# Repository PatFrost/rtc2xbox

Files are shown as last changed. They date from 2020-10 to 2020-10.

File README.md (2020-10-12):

# RTC2Xbox
<p align="center">
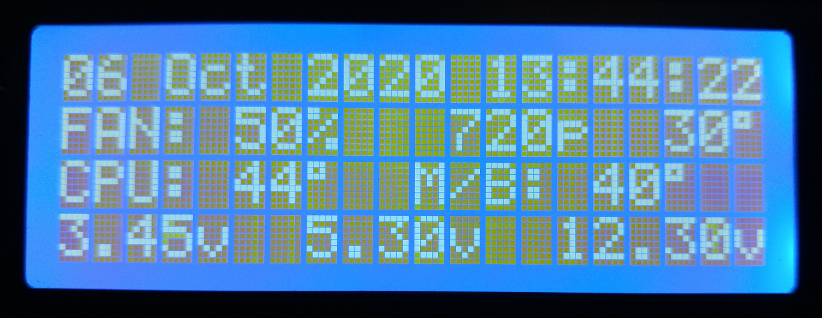
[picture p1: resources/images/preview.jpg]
Preview
  
</p>

<p align="center">
  
  
  <a href="http://hits.dwyl.com/PatFrost/rtc2xbox">HitCount</a>
</p>
<p align="center">
  
  
  
</p>

RTC2Xbox is inspired and based on [spi2par2019](https://github.com/Ryzee119/spi2par2019) by Ryzee119.
<br>It's a LCD mod for the original Xbox without modchip.

# New Features!
  - Display date and time with real time clock.
  - Display temperature ambient from a thermistor.
  - Display voltages 3.3v 5.0v 12.0v

**Note**
  - Delay for displaying fan speed, temp° of CPU, M/B and resolution is 2 secs to 30 secs for first time.
    <br>And the next times is 2 secs to 10 secs. It's depend of the SMBus if is busy or not.
  - Contrast and backlight are controlled by only one potentiometer in same time.

### Parts list
| Part | Qty | Shops | Optional |
| ---- | :----: | ----- | ----- |
| Arduino Pro Micro Leonardo **5V/16Mhz** | **2** | [Any clones will work](https://www.amazon.com/s?k=Arduino+Pro+Micro+Leonardo+5V%2F16Mhz&ref=nb_sb_noss)<br> Make sure they're the **5V/16Mhz** variant. |
| Adafruit **DS1307** Real Time Clock  | **1** | [Any clones will work](https://www.amazon.com/Adafruit-3296-DS1307-Clock-Breakout/dp/B01MG3NEWF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) <br>I don't recommend chinese versions. 1 of 10 work correctly. |
| LCD 2004 | **1** | [Any LCD 20x4 will work](https://www.amazon.com/s?k=LCD+2004&ref=nb_sb_noss) <br>If IIC/I2C/TWI Serial Interface Adapter is present, remove it. |
| Resistor 10kΩ | **6** |[Any Resistor 10kΩ](https://www.amazon.com/BOJACK-Single-Resistor-Resistors-200pcs/dp/B07PGHP69F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) <br>Or any resistor in series with total values 10kΩ |
| Resistor 25kΩ | **1** | [Any Resistor 25kΩ](https://www.amazon.com/s?k=Resistor+25k%E2%84%A6&ref=nb_sb_noss) <br>Or any resistor in series with total values 25kΩ |
| Thermistor 10kΩ | **1** | [Any Thermistor 10kΩ](https://www.amazon.com/s?k=Thermistor+10k%E2%84%A6&s=price-asc-rank&qid=1602342606&ref=sr_st_price-asc-rank) | **Optional** |
| Potentiometer 10kΩ | **1** |[Any Potentiometer 10kΩ](https://www.amazon.com/s?k=Potentiometer+10k%E2%84%A6&ref=nb_sb_noss)|
| Capacitor 220uf | **1** | [Any Capacitor](https://www.amazon.com/s?k=Capacitor+220uf&ref=nb_sb_noss) | **Optional** |
| Connector Plug 4 pin | **1** | [Any 4 Pin Connector Plug Female & Male.](https://www.amazon.com/2-0MM-Female-Single-Connector-Wires/dp/B0732MMD7K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) |
| Perforated Proto Board | **1** | [Any proto board](https://www.amazon.com/s?k=perfboard&ref=nb_sb_noss) | **Optional** |
| Some Wires | **∞** | [Any wires](https://www.amazon.com/s?k=wires+26+AWG&ref=nb_sb_noss) |

### Software Installation
RTC2Xbox uses the open-source Arduino Software (IDE):
  - [Download the Arduino IDE](https://www.arduino.cc/en/Main/Software#download) And install it!

**LiquidCrystal Library**
Open the IDE and click to the "Sketch" menu and then Include Library > [Manage Libraries.](https://www.arduino.cc/en/guide/libraries#toc3)
1. In `Filter your search...` enter `LiquidCrystal` install it or update it.
2. In `Type` select `updatable` and update all libraries which would appear.

**RTC2Xbox Library**
  - [Clone this repository to your PC](https://github.com/PatFrost/rtc2xbox.git)
  - [Or Download Zip](https://github.com/PatFrost/rtc2xbox/archive/master.zip)
    <br>Extract to `rtc2xbox` or rename `rtc2xbox-master` to `rtc2xbox`

### RTC Installation & Programming
1. **Connect Slave (Pro Micro) to RTC DS1307** 
    <br><br>
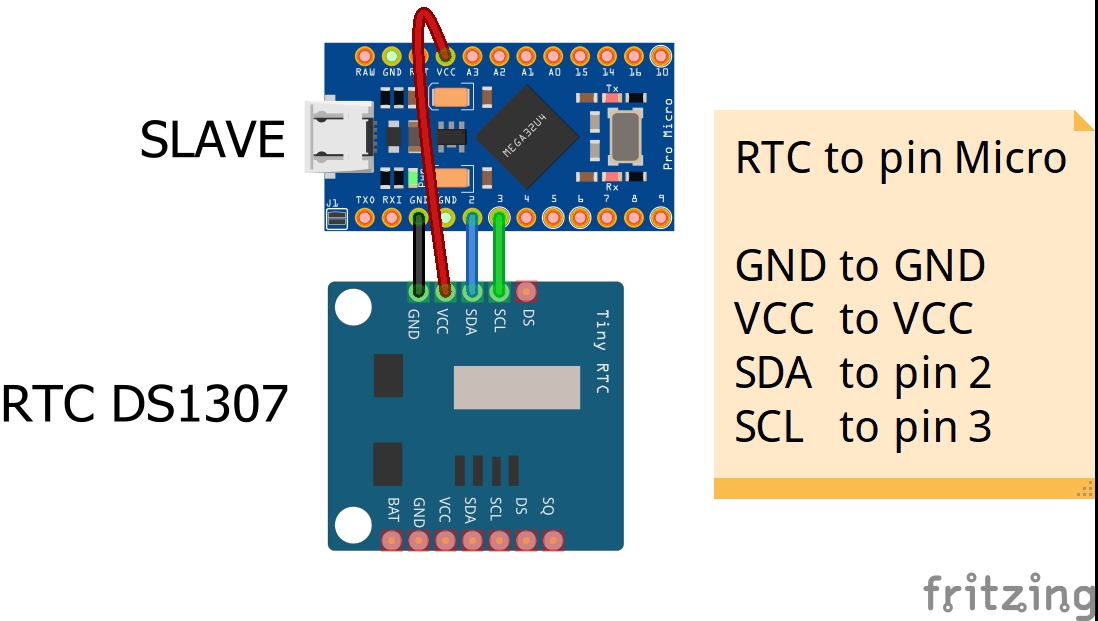
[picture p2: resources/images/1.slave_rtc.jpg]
    
    <br><br><br>
2. **Program Slave (Pro Micro), open `/rtc2xbox/rtc2xbox_slave/rtc2xbox_slave.ino` with Arduino IDE.**<br>
    Uncomment below, if you want force adjust date time.
    Only set the datetime one time.
    ```c++
    // #define FORCE_ADJUST_DATETIME
    ```
    for
    ```c++
    #define FORCE_ADJUST_DATETIME
    ```
    and ajust time at line 30. You can add 30 sec for compiling and uploading.
    ```c++
    uint8_t hour  =   11; // 0-23
    uint8_t min   =    0; // 0-59
    uint8_t sec   =    0; // 0-59

    uint8_t day   =   10; // 1-31
    uint8_t month =   10; // 1-12
    uint16_t year = 2020; // 2000-2099
    ```
    
3. **Set the Board Type the Arduino Leonardo and the port correctly.**
    <br><br>
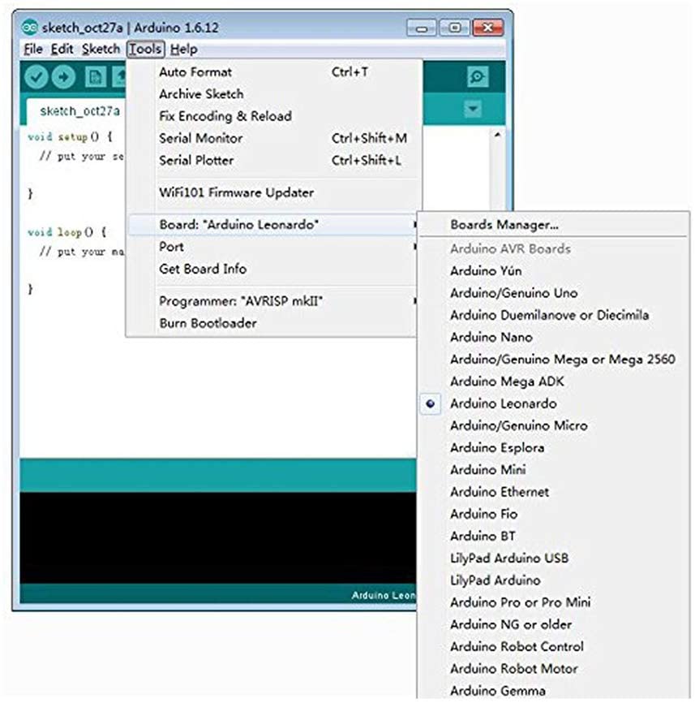
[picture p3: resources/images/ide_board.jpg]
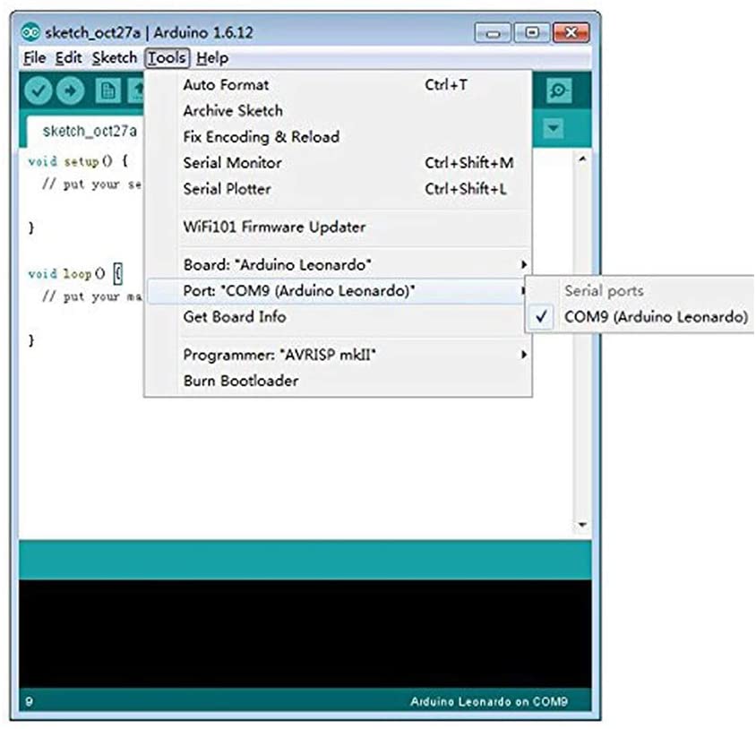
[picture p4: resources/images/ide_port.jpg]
    
    <br><br><br>
4. **Compile by clicking the tick in the top left.**<br>
    Check the console output it has compiled successfully
5. **Connect a Micro USB cable between the Slave (Pro Micro) and the PC.**
6. **Click the upload button and confirm successful.**
7. **Disconnect Slave (Pro Micro)**
    * comment `#define FORCE_ADJUST_DATETIME`. Remember, only set the datetime one time.
        ```c++
        // #define FORCE_ADJUST_DATETIME
        ```
****
8. **Program Master (Pro Micro), open `/rtc2xbox/rtc2xbox.ino` with Arduino IDE.**<br>
    Uncomment below to make the in-game temp readouts display in Fahrenheit.
    ```c++
    // #define USE_FAHRENHEIT
    ```
    for
    ```c++
    #define USE_FAHRENHEIT
    ```
9. **Compile by clicking the tick in the top left.**<br>
    Check the console output it has compiled successfully
10. **Connect a Micro USB cable between the Master (Pro Micro) and the PC.**
11. **Click the upload button and confirm successful.**
12. **Disconnect Master (Pro Micro)**

### Hardware Installation
1. **Connect Master (Pro Micro) to LCD, Potentiometer and Thermistor (Optional)**
    <br><br>
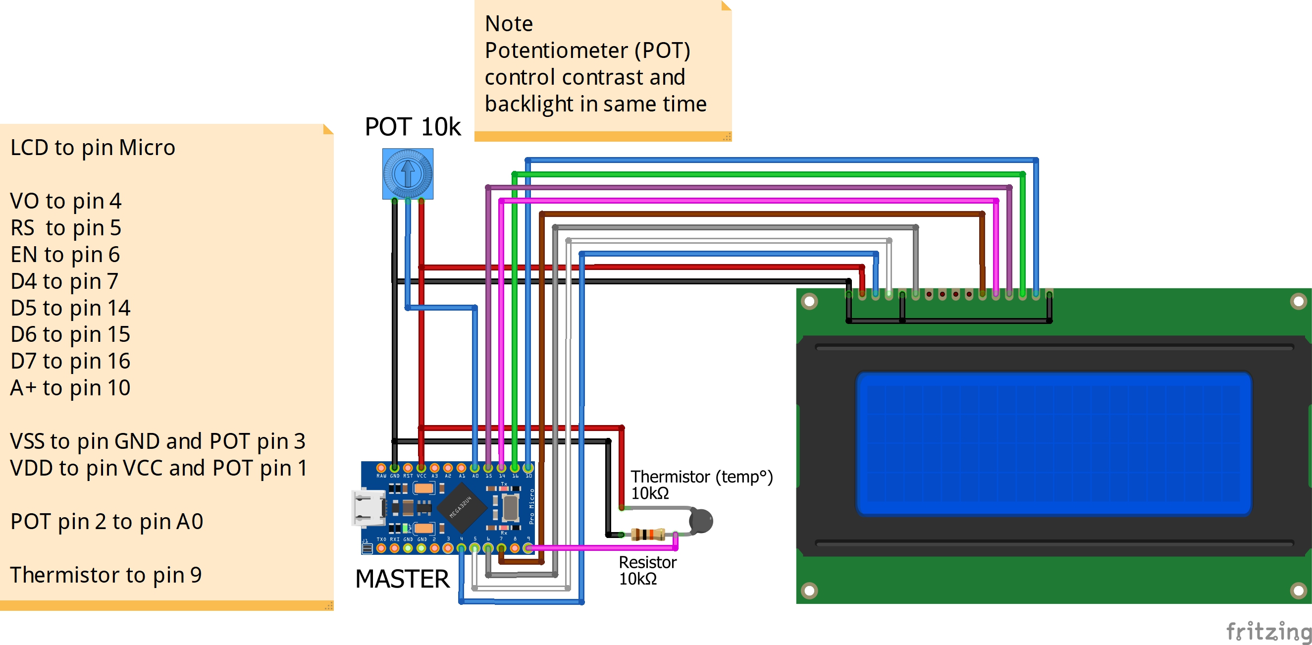
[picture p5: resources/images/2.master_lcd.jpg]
    
    <br><br><br>
2. **Connect Master (Pro Micro) for voltages reading**
    <br><br>
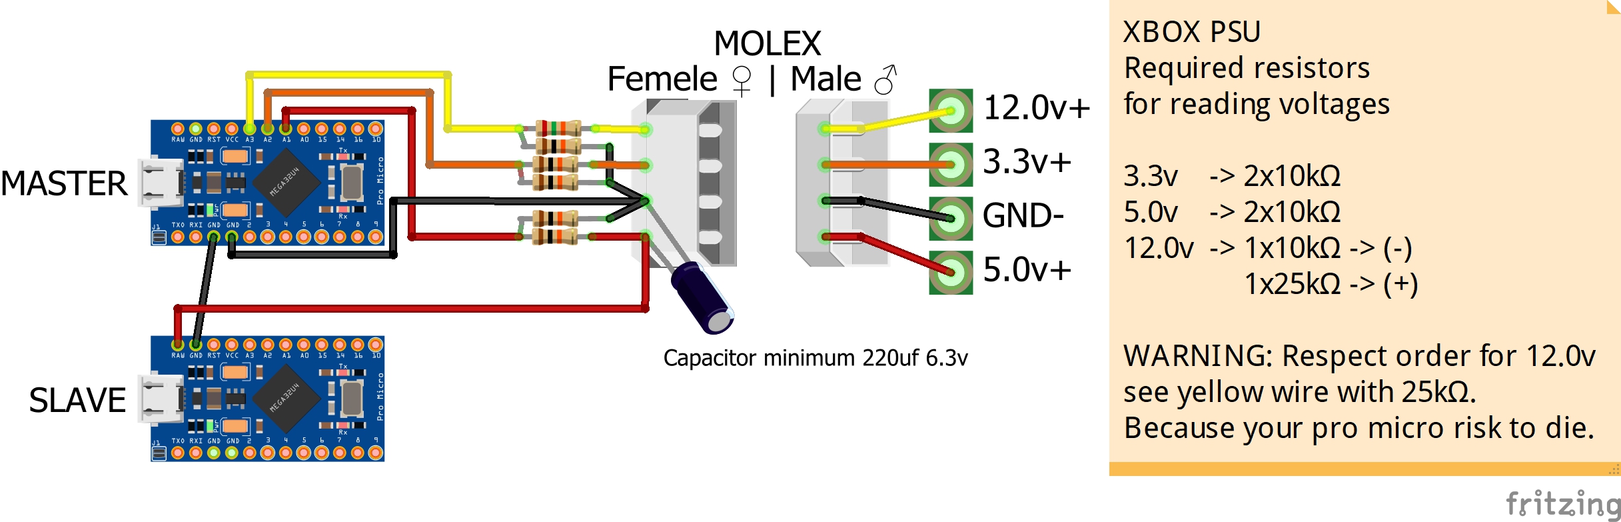
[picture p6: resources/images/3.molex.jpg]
    
    <br><br><br>
3. **Connect Master (Pro Micro) to Slave (Pro Micro)**
    <br><br>
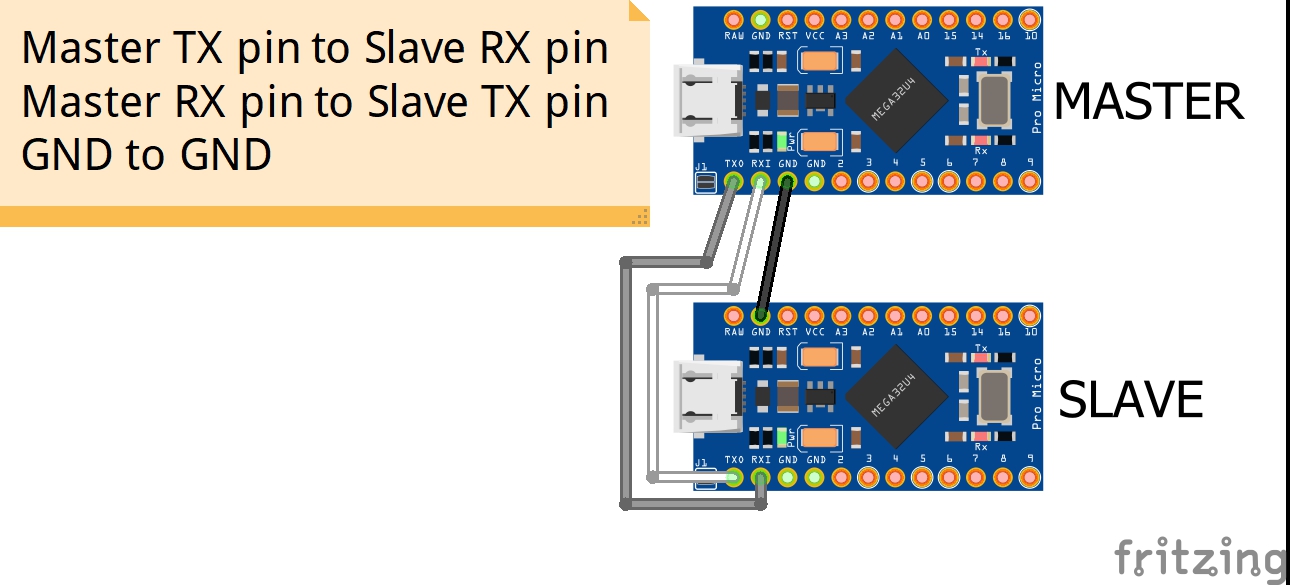
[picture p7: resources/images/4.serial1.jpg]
    
    <br><br><br>
4. **Connect Master (Pro Micro) to Xbox LPC**
    <br><br>
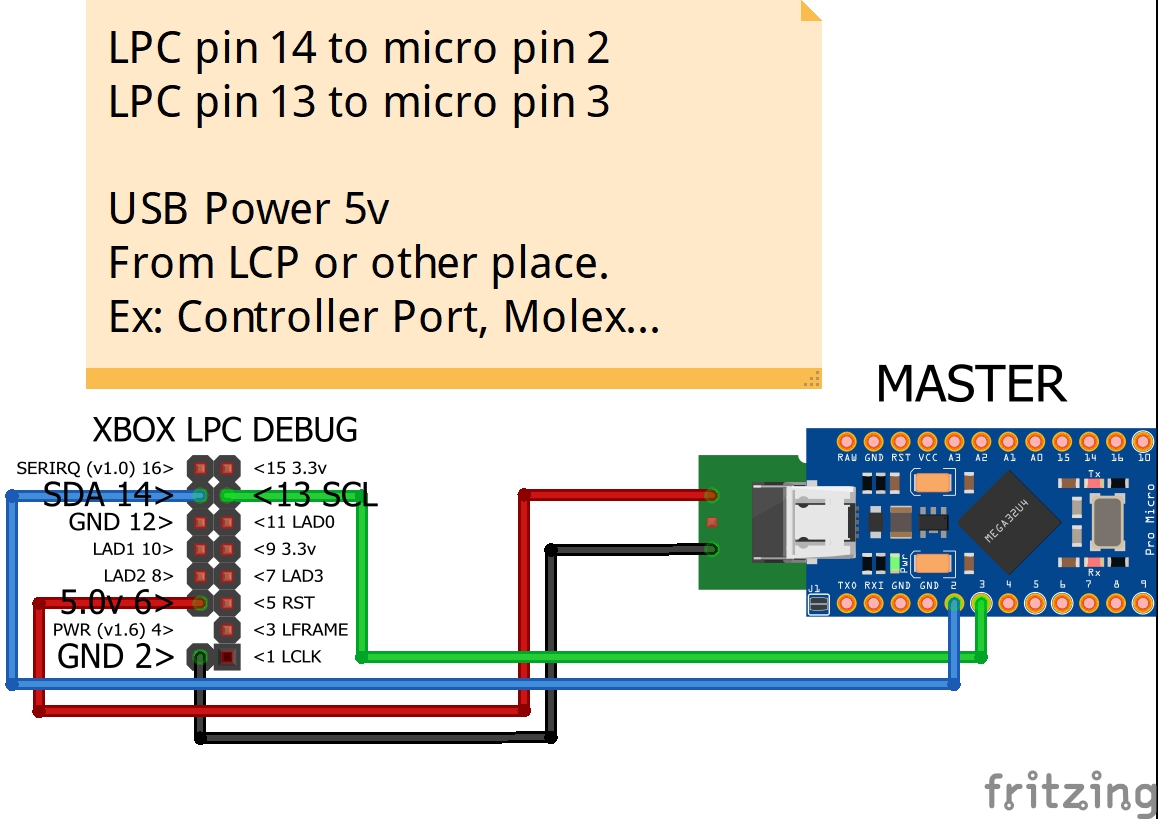
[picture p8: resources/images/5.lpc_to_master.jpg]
    
    <br><br><br>
****
<br><br>
**Final Result**<br>
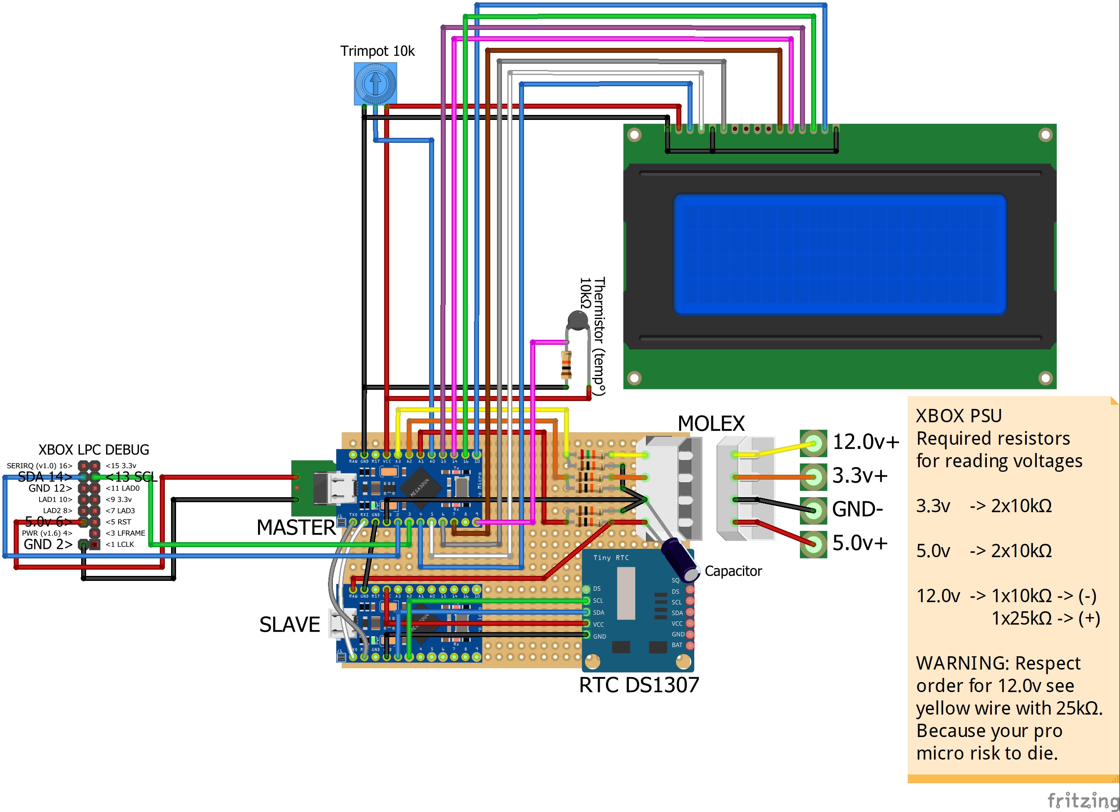
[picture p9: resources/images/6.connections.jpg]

<br><br><br>

### Development
Want to contribute? Great!<br>
[Open pull requests](https://github.com/PatFrost/rtc2xbox/pulls)

### Warning
If you want to reprogram the Master (Pro Micro) and/or the Slave (Pro Micro)!<br>
Take no chances, **disconnect** plug for `voltages reading` and `wires between` Xbox LPC and Master (Pro Micro).

### Legal
This article is intended to provide general information.<br>
Please always read and follow the labels/instructions that accompany your products.<br>
I cannot be held responsible for any injuries or damages caused by this activity.

<br><br>
**Cheers!!!**

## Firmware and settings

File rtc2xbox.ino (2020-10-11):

// Uncomment below to make the in-game temp readouts display in Fahrenheit.
// #define USE_FAHRENHEIT


#include <LiquidCrystal.h>
#include "src/Log.h"       // Used in debug mode
#include "src/xboxsmbus.h" // Lib and Xbox Functions by Ryzee119

// Max 5v Vout and (REQUIRED) Protect by Resistor (R2 / (R1 + R2))
#define SENSOR_3V()   (analogRead(A2)) // Resistor (10k / 10k + 10k)) = 1.65 vout of  3.3v
#define SENSOR_5V()   (analogRead(A1)) // Resistor (10k / 10k + 10k)) = 2.50 vout of  5.0v
#define SENSOR_12V()  (analogRead(A3)) // Resistor (10k / 25k + 10k)) = 3.43 vout of 12.0v
#define SENSOR_POT()  (analogRead(A0)) // Potentiometer 10kΩ to adjust contrast and backlight in same time
#define SENSOR_TEMP() (analogRead(9))  // Temperature with thermistor 10kΩ and resistor 10kΩ

// set up a new (soft) serial port (master to slave, slave to master)
// https://www.arduino.cc/reference/en/language/functions/communication/serial/
#define Master Serial1


// Declare our LCD object: LiquidCrystal(RS, E, D4, D5, D6, D7)
LiquidCrystal LCD(5, 6, 7, 14, 15, 16);

String LCD_LINES[4];

int BACKLIGHT_PIN   = 10;   // Backlight PIN 16bits
int BACKLIGHT_VALUE = 255;  // 0-255 Higher is brighter.

int CONTRAST_PIN    = 4;    // Contrast PIN 8bits (without flickering)
int CONTRAST_VALUE  = 127;  // 0-127 Higher is brighter on PIN 8bits.
                            // 0-255 Lower is higher contrast on PIN 16bits.

char DEGREE         = 223;  // ° symbol
// char OHMS           = 244;  // Ω symbol
// char OHMS           = 0xF4; // Ω symbol

uint32_t WELCOME_TIME;      // Timer for show welcome message (1 hour)

// Custom chars
byte PUNISHER[] = { B00000, B01110, B10101, B11011, B01110, B01010, B01010, B00000 };


void getDateTime() {
  String str = "";
  while (Master.available()) {
    delay(5);
    char c = Master.read();
    str += c;
  }
  if (str.length() >= 19) {
    LCD.setCursor(0, 0);
    LCD.print(str.substring(0, 20));
    LOG(F("DateTime: ")); LOG_END(str.substring(0, 20));
  }
}

void setup () {
  // init Serial port
  Master.begin(9600);
  delay(100);
  // Master.println("Master: Hello Slave");

  // Start log output if enabled
  LOG_BEGIN();

  // Speed up PWM frequency. Gets rid of flickering
  TCCR1B &= 0b11111000;
  TCCR1B |= (1 << CS00);  // Change Timer Prescaler for PWM

  setContrastBacklight(true); // Contrast and background control of the LCD

  // Start LCD
  LCD.begin(20, 4);
  LCD.createChar(0, PUNISHER);
  delay(2);
  LCD.noCursor();
  welcomeMessage();
  WELCOME_TIME = millis();

  SMBusBegin();
}

void loop () {
  // Debug infos
  LOG((SENSOR_POT() / 100.0)); LOG_END(F(" k"));
  LOG(((SENSOR_POT() + 0.5) * 10.0 / 1024.0)); LOG_END(F(" k"));
  LOG(((SENSOR_POT() + 0.5) *  5.0 / 1024.0)); LOG_END(F("v"));
  LOG_END();

  setContrastBacklight(false);

  if (millis() - WELCOME_TIME >= 3600000) { // 1 hour
    welcomeMessage();
    WELCOME_TIME = millis();
  }

  // Check that i2cBus is free
  if (!i2cBusy()) {
    LCD_LINES[1]  = getXboxFanSpeed();         // Xbox SMBus
    LCD_LINES[1] += getXboxResolution();       // Xbox SMBus
#ifdef USE_FAHRENHEIT
    LCD_LINES[2] = getXboxTemperatures(true);  // Xbox SMBus
#else
    LCD_LINES[2] = getXboxTemperatures(false); // Xbox SMBus
#endif
  }

  // Send the information to the LCD
  /* LINE 1 */
  getDateTime();

  /* LINE 2 */
  LCD.setCursor(0, 1);
  LCD.print(LCD_LINES[1]);
  LCD.setCursor(17, 1);
  LCD.print(round(getTemperature()));
  LCD.print(DEGREE); // ° symbol

  /* LINE 3 */
  LCD.setCursor(0, 2);
  LCD.print(LCD_LINES[2]);
  // LCD.print(I2C_CHECK_COUNT);

  /* LINE 4 */
  LCD.setCursor(0, 3);
  // LCD.print(F("3.30v 5.00v 12.00v  ")); // voltages
  double v3, v5, v12;
  getVoltages(v3, v5, v12);
  LCD.print(v3);  LCD.print(F("v  "));
  LCD.print(v5);  LCD.print(F("v  "));
  LCD.print(v12); LCD.print(F("v"));

  delay(1000);
}

float getTemperature() {
  // See http://en.wikipedia.org/wiki/Thermistor for explanation of formula
  float temp = log(((10240000/SENSOR_TEMP()) - 10000));
  temp = 1 / (0.001129148 + (0.000234125 * temp) + (0.0000000876741 * temp * temp * temp));
  temp = temp - 273.15; // Convert Kelvin to Celcius
#ifdef USE_FAHRENHEIT
  temp = (temp * 1.8 + 32.0);
#endif
  return temp;
}

void getVoltages(double & v3, double & v5, double & v12) {
  // read the raw data coming in on analog pin A1, A2, A3
  v3 = ((SENSOR_3V() + 0.5) * 5.0 / 1024);
  if ((int)v3 > 0) v3 += (3.3 - (3.3 * (10.0 / (10.0 + 10.0))));

  v5 = ((SENSOR_5V() + 0.5) * 5.0 / 1024);
  if ((int)v5 > 0) v5 += (5.0 - (5.0 * (10.0 / (10.0 + 10.0))));

  v12 = ((SENSOR_12V() + 0.5) * 5.0 / 1024);
  if ((int)v12 > 0) v12 += (12.0 - (12.0 * (10.0 / (25.0 + 10.0))));
}

void setContrastBacklight(bool force) {
  int value = map(SENSOR_POT(), 0, 1023, 0, 255);
  if (force || value != BACKLIGHT_VALUE) {
    BACKLIGHT_VALUE = value;
    analogWrite(BACKLIGHT_PIN, BACKLIGHT_VALUE);
    LOG(F("BACKLIGHT_VALUE: ")); LOG_END(BACKLIGHT_VALUE);
  }
  // value = map(SENSOR_POT(), 0, 1023, 255, 0); // if pin is 16bits use this and remove ( / 2)
  if (force || value / 2 != CONTRAST_VALUE) {
    CONTRAST_VALUE = value / 2;
    analogWrite(CONTRAST_PIN, CONTRAST_VALUE);
    LOG(F("CONTRAST_VALUE: ")); LOG_END(CONTRAST_VALUE);
  }
}

void welcomeMessage() {
  /* totals 12 secs */
  int speed = 50;
  // Draw Punisher 2200ms
  LCD.setCursor(0, 0);
  for (int i=0; i<20; i++) {
    LCD.write(byte(0));
    delay(speed);
  }
  LCD.setCursor(19, 1);
  LCD.write(byte(0));
  delay(speed);
  LCD.setCursor(19, 2);
  LCD.write(byte(0));
  delay(speed);
  for (int i=19; i>=0; i--) {
    LCD.setCursor(i, 3);
    LCD.write(byte(0));
    delay(speed);
  }
  LCD.setCursor(0, 2);
  LCD.write(byte(0));
  delay(speed);
  LCD.setCursor(0, 1);
  LCD.write(byte(0));
  delay(speed);

  // Draw Title and Author 1800ms + 3000ms
  typewriter("     RTC2Xbox     ", speed, 1, 1);
  typewriter("     by Frost     ", speed, 1, 2);
  delay(3000);

  // Draw Special thanks 2700ms + 2300ms
  typewriter("  Special Thanks  ", speed, 1, 1);
  typewriter("   to  Ryzee119   ", speed, 1, 2);
  delay(500);
  LCD.setCursor(1, 2);
  LCD.print(F("                  "));
  LCD.setCursor(1, 1);
  LCD.print(F("   to  Ryzee119   "));
  typewriter(" for  spi2par2019 ", speed, 1, 2);
  delay(1800);

  LCD.clear();
}

void typewriter(char * line, int speed, int x, int y) {
  LCD.setCursor(x, y);
  for (int l=0; l <=strlen(line); l++) {
    LCD.print(line[l]);
    delay(speed);
  }
}

void clearLine(int line) {
  LCD.setCursor(0, line);
  LCD.print(F("                    "));
  LCD.setCursor(0, line);
}

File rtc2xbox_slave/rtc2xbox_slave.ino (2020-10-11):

// Slave for RTC, because not work with SMWire for xbox and cause conflict...

// Uncomment below, if you want force adjust date time. Only set the datetime one time.
// #define FORCE_ADJUST_DATETIME

#include <Wire.h>
#include "src/DS1307/DS1307.h"

// set up a new (soft) serial port (master to slave, slave to master)
// https://www.arduino.cc/reference/en/language/functions/communication/serial/
#define Slave Serial1

DS1307 clock;

const char strMonth[12][4] = { "Jan", "Feb", "Mar", "Apr", "May", "Jun",
                               "Jul", "Aug", "Sep", "Oct", "Nov", "Dec" };

void setup() {
  // init Serial port
  Slave.begin(9600);
  delay(100);
  // Slave.println("Slave: Hello Master");

  // Serial.begin(57600);
  // delay(1000);
  // while(!Serial); // wait for serial port to connect - needed for Leonardo only

  // only set the date+time one time. You can add 30 sec for compiling and uploading.
#ifdef FORCE_ADJUST_DATETIME
  uint8_t hour  =   13; // 0-23
  uint8_t min   =    0; // 0-59
  uint8_t sec   =    0; // 0-59

  uint8_t day   =   11; // 1-31
  uint8_t month =   10; // 1-12
  uint16_t year = 2020; // 2000-2099

  clock.set(sec, min, hour, day, month, year);
#endif

  // stop/pause RTC
  // clock.stop();

  // start RTC
  clock.start();
}

void loop() {
  char datetime[21]; // Fomatted data for printing to LCD
  uint8_t sec, min, hour, day, month;
  uint16_t year;

  // get time from RTC
  clock.get(&sec, &min, &hour, &day, &month, &year);
  snprintf(datetime, sizeof datetime, "%02d %s %4d %02d:%02d:%02d",
                                      day, strMonth[month-1], year,
                                      hour, min, sec);
  // Serial.print(F("Slave: "));
  // Serial.println(datetime);
  Slave.print(datetime); // send datetime to Master

  // wait a second
  delay(1000);
}

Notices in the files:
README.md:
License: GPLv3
